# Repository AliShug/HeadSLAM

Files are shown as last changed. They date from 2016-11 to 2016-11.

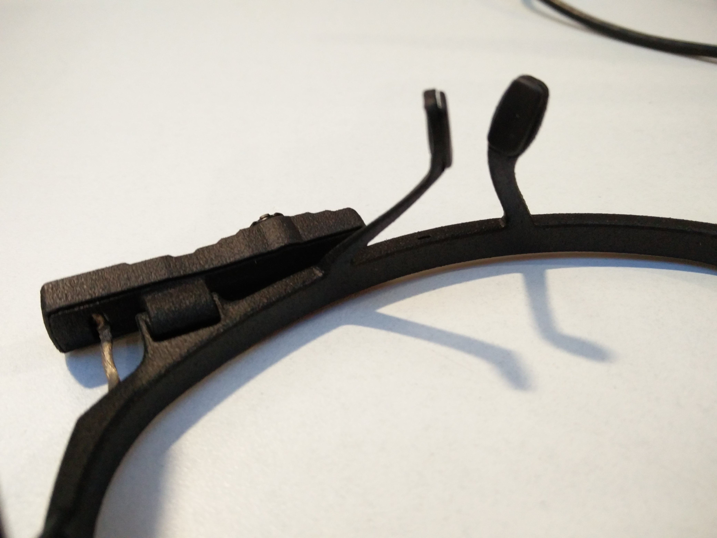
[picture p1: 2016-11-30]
reference/camera_back.jpg

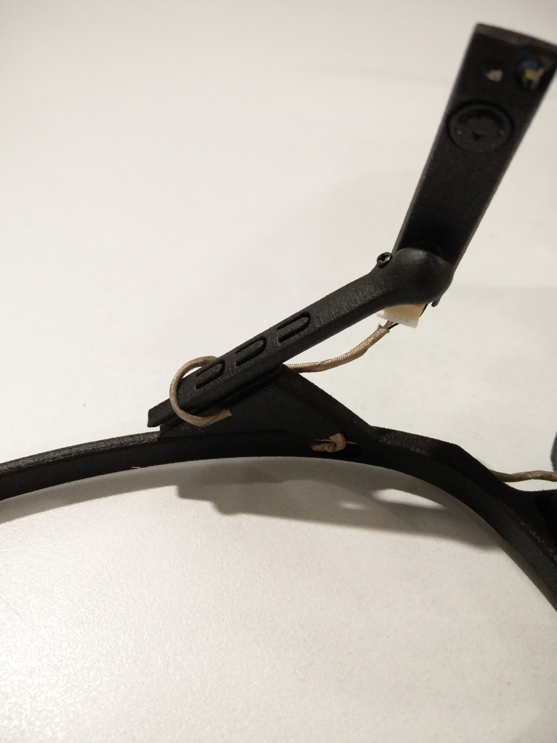
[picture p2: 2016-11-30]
reference/eye-tracker.jpg

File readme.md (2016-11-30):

This is a set of prototype design files for a head-mounted combined SLAM/eye-tracking system, based on the Pupil labs headset. The designs are intended to be 3D-printed - see [here](3d-printing.md) for more details.

# Files
Individual components are contained in Inventor part (IPT) files, with some files containing more than one solid body (these need to be separated out for 3D printing). Some parts are derived from others, which means changes to the root part affect the derived part. This is true for parts representing individual solids from a multi-body part, as well as some other parts: for example, the Pupil-FULL part derives from the Pupil part.

Assemblies show how the parts fit and connect together. An assembly is provided for each of the prototypes, with two different versions for the second prototype.

# Assembly
The designs use mainly metric M2 and some M3 screws and nuts. Slots are provided in several parts for M2 nuts, which should be filled by pushing these nuts into place before assembly.

The prototypes clamp directly onto the edges of the Pupil headset. Screw the clamps on most of the way before mounting, then line up the parts by matching the curve of the front of the headset to the curve in the mounting. Tighten the screws fully to secure the assembly.

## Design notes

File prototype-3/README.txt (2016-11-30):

Working prototype, uses a clamping mechanism to hold the entire assembled Xtion
heatsink, including the factory-mounted PCB and cameras.

The design sacrifices weight savings for ease of mounting and use; this
prototype should not require calibration and dissipates heat as well or better
than the fully assembled Xtion.

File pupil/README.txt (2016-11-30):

While care has been taken to be as accurate as possible, these models are
reverse-engineered using hand measurements and rough photographs of the pupil
headset, and as such they are APPROXIMATE. The actual headset may differ from
these designs by as much as a 1-2mm, notably in the precise shape of the curves
and the nose-rests.

The "full" model lacks the characteristic camera and eye-tracker, but shows
where these are mounted.

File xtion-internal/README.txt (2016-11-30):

While care has been taken to be as accurate as possible, these models are
reverse-engineered using hand measurements, and as such they are APPROXIMATE.
This mostly affects the heatsink, which was modelled with straight sides which
should in fact be slightly tapered.

The heatsink model lacks some holes and mounting points for the PCB. The
heatsink's precise design may also differ slightly between different models of
the Xtion.

With the exception of connection points, the PCB model lacks representation on
on-surface components. Care should be taken when designing e.g. mounts for the
PCB to account for the extra 1-2mm of clearance needed for these parts, on BOTH
sides of the board. Areas immediately (2-3mm) around the screw holes are clear
on both sides.

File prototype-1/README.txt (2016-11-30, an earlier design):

Lightweight design which mounts well (the clamps remained unchanged in the later
prototypes), but with several problems. The PCB was intended to be mounted flat,
which was impossible since the surface components on the board prevented it from
being placed flush. The mounting of the cameras and projector directly onto a
3D-printed part also proved impractical, since the Xtion would have to be
extensively re-calibrated.

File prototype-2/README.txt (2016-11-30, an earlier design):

This prototype still had the problem of requiring a difficult recalibration, and
didn't provide sufficient heat dissipation. A minor redesign allowed use of a
modified (cut-down) heatsink as part of the design, but removing the cameras
from their mountings (even when replacing them in their original positions)
would still have negatively affected calibration.

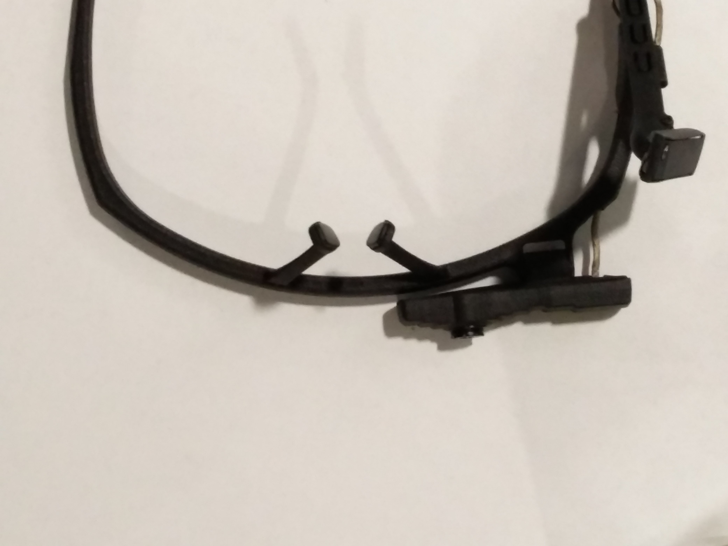
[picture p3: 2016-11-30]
reference/pupil_bottom_close.jpg

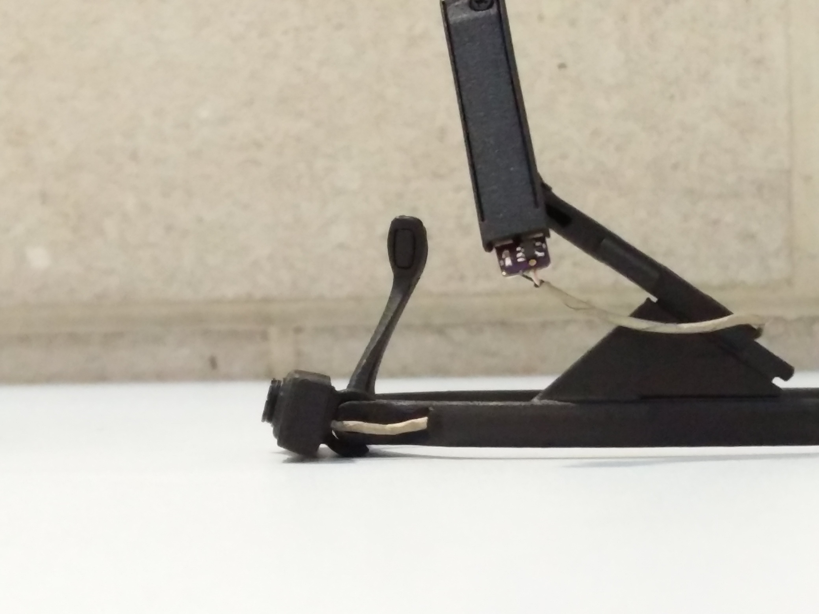
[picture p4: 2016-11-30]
reference/rest_side.jpg

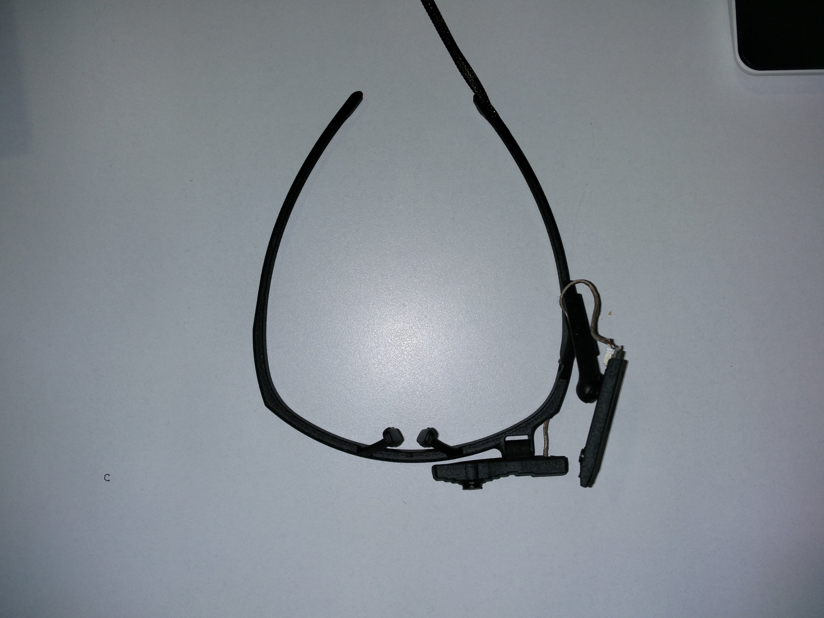
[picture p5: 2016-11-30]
reference/pupil_bottom.jpg

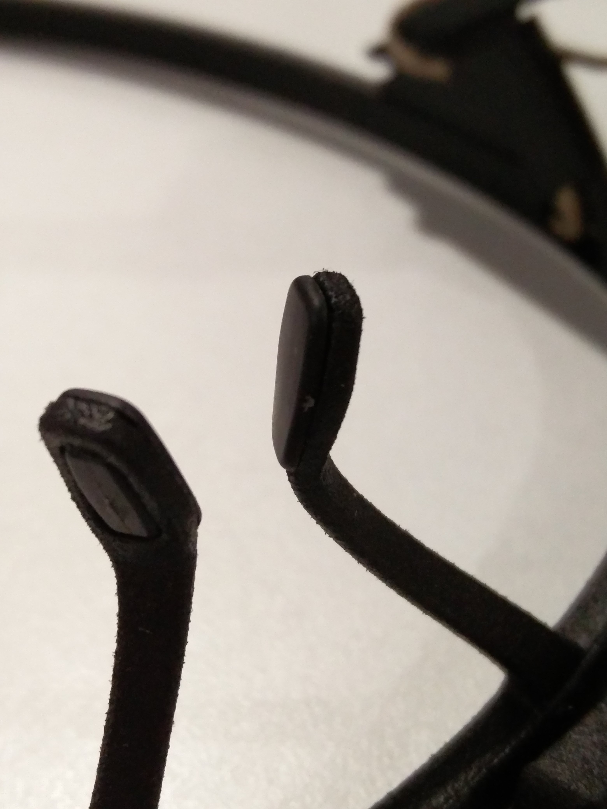
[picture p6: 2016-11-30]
reference/rest_pads.jpg

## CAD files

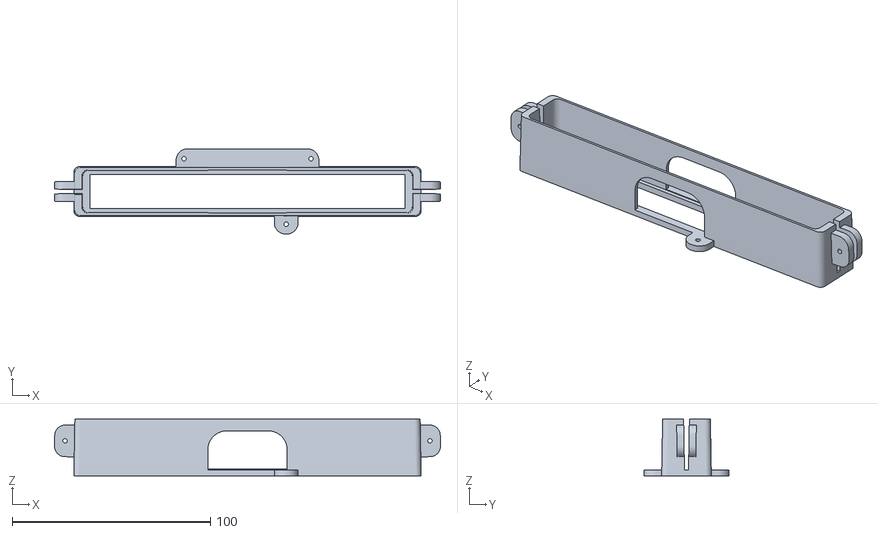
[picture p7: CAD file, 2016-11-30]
stl/final/xtion_heatsink_mount_FULL.stl
194.6 x 43.0 x 28.5

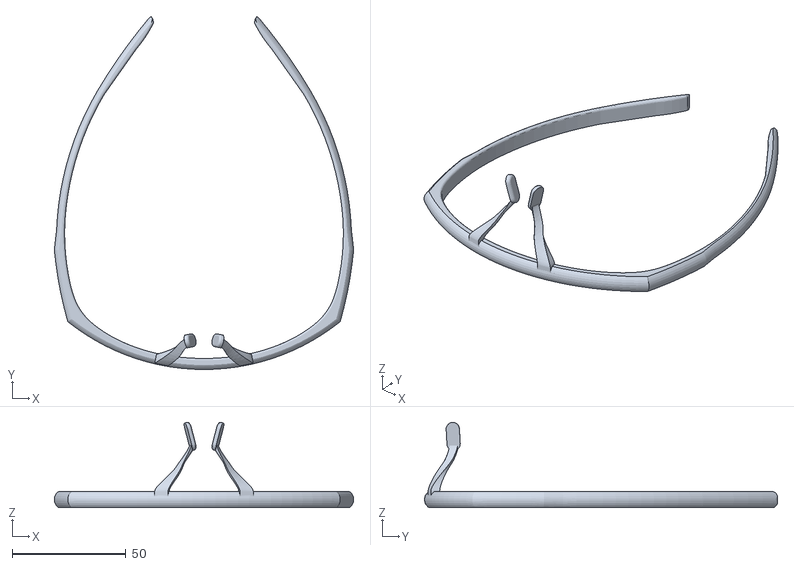
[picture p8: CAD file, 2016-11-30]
stl/pupil_frame.stl
131.9 x 155.5 x 37.6

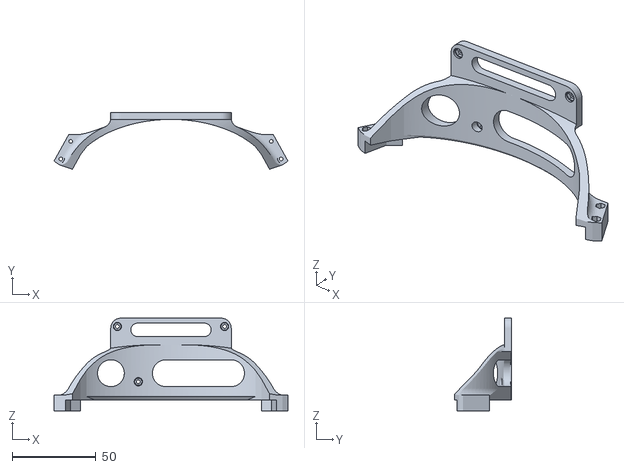
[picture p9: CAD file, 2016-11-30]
stl/final/head_mount_v3_core.stl
139.8 x 33.8 x 55.4

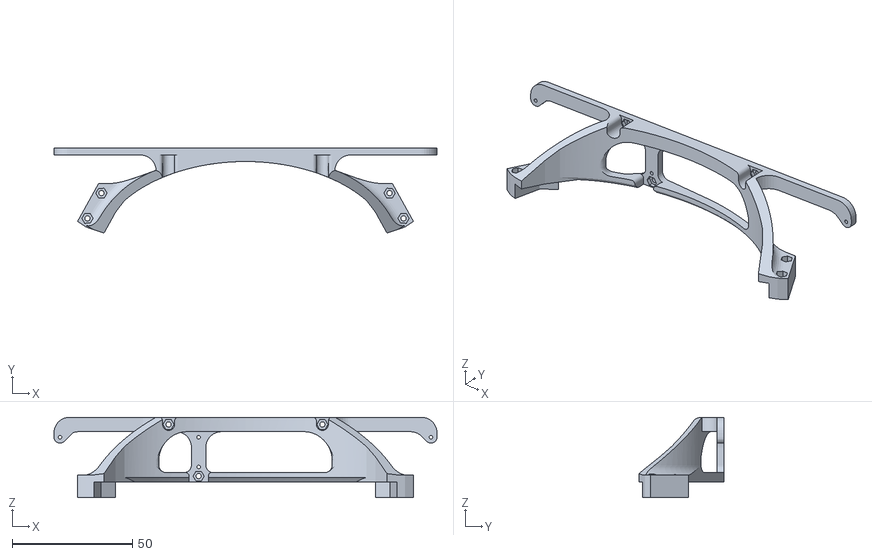
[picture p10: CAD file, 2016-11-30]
stl/mounting_core_v2.stl
159.4 x 35.5 x 33.5

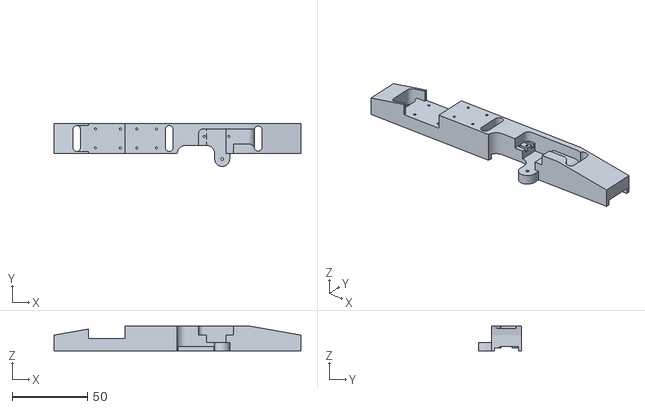
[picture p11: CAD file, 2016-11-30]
stl/xtion_custom.stl
164.0 x 28.6 x 16.3

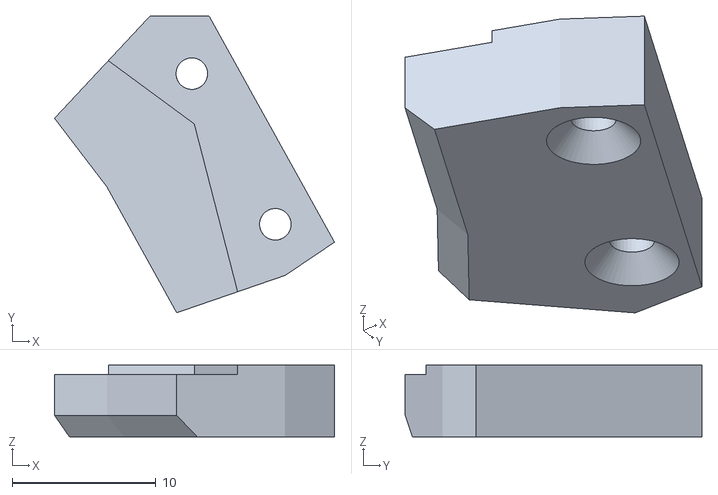
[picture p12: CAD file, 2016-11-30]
stl/mounting_clamp_r.stl
19.5 x 20.7 x 5.00

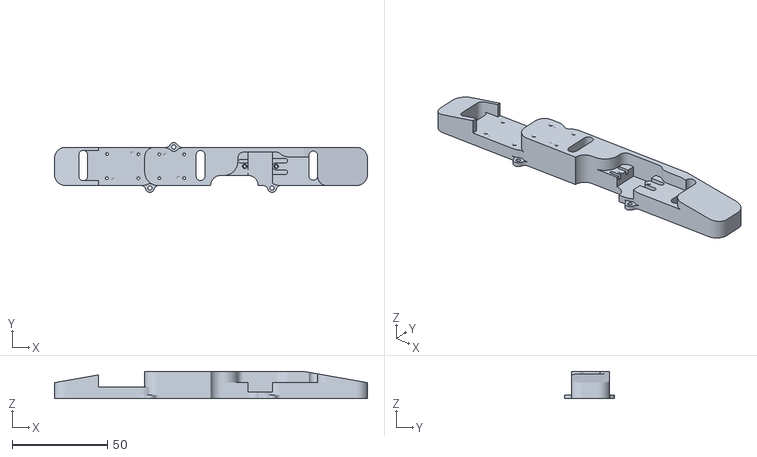
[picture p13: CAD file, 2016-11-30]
stl/xtion_custom_v2.stl
164.0 x 26.1 x 14.3

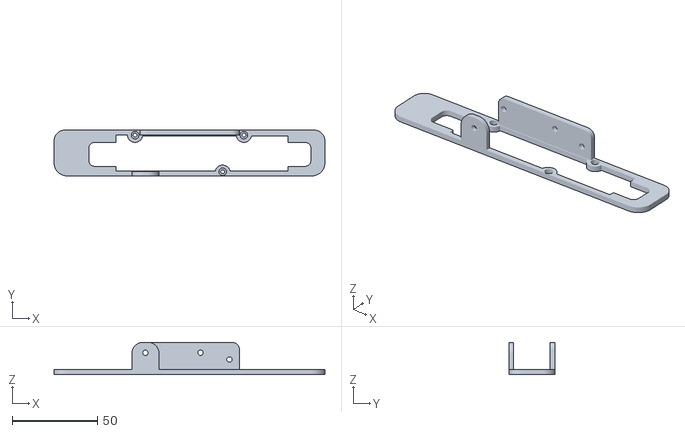
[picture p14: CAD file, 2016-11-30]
stl/xtion_custom_heatsink_mount.stl
159.4 x 27.0 x 19.0

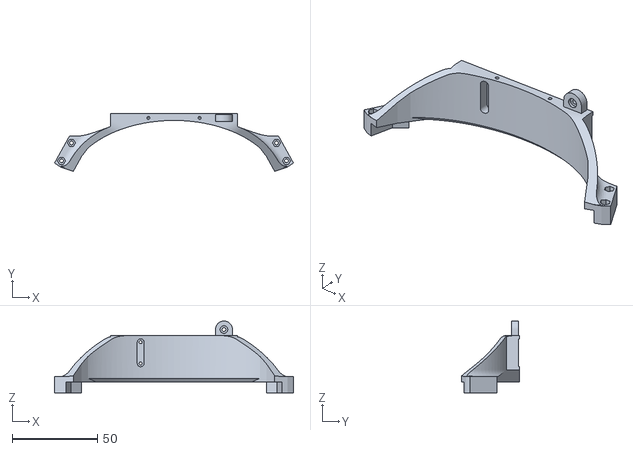
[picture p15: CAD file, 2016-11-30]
stl/mouting_core.stl
139.8 x 33.8 x 42.1

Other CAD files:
prototype-1/mounting.ipt
prototype-1/mounting_clamp_l.ipt
prototype-1/mounting_clamp_r.ipt
prototype-1/mouting_core.ipt
prototype-1/xtion_custom.ipt
prototype-1/xtion_custom_assembly.iam
prototype-2/head_mount_v2.ipt
prototype-2/mounting_core_v2.ipt
prototype-2/xtion_custom_assembly_v2.iam
prototype-2/xtion_custom_assembly_v2_heatsink_mod.iam
prototype-2/xtion_custom_heatsink_mount.ipt
prototype-2/xtion_custom_v2.ipt
prototype-2/xtion_heatsink_mod.ipt
prototype-3/head_mount_v3_FULL.ipt
prototype-3/head_mount_v3_core.ipt
prototype-3/xtion_custom_assembly_v3_FULL.iam
prototype-3/xtion_heatsink_mount_FULL.ipt
pupil/pupil_frame.ipt
pupil/pupil_frame_full.ipt
xtion-internal/xtion_heatsink.ipt
xtion-internal/xtion_internal.iam
xtion-internal/xtion_ir_cam.ipt
xtion-internal/xtion_mainboard.ipt
xtion-internal/xtion_projector.ipt
xtion-internal/xtion_rgb_cam.ipt

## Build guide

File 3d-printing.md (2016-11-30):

# 3D Printing
Use best practices for the printer you're working with - these are general guides for printing the parts in this repository.

## Conversion
### Export
Inventor part files (.IPT) must be exported to a 3D format, typically STL, to be "sliced" in a program like Cura and 3D printed. Exporting can be done using the file menu (*File->Export->CAD Format*), or using the 3D printing environment (*Environments->3D Printing*) in Inventor Pro. Make sure to use **millimetres** as the unit for exporting, to ensure the scaling of the part is accurate.

### Splitting parts
The main mounting part in each of the prototypes is comprised of three separate solid bodies (the core and two clamps) which must be printed separately. One way to do this is to derive a new part from a *single* solid body in the multi-body part, using *Manage->Make Part*. The isolated part can then be exported and printed as normal.

## Supports
Many of the parts have distinct overhangs and holes which **must** be supported when printing: please use support-generation options in your slicing program, and enable these supports for all surfaces - *not just from the printing bed*.

If your printer requires it, use a 'raft' for bed adhesion and level printing. On an Ultimaker 2/3 this isn't necessary, but you should still use a 'brim' for the larger parts.

## Orientation
The parts should be oriented on the printing bed to minimise the amount of support necessary, and either in line with or at 90 degrees to any screw holes in the part (don't print at a 45 degree slant!). If the part has a large, flat surface, use this as the base.

## Quality
These parts need to fit together fairly precisely, and must be consistently strong in order to flex and mount properly. Use 0.1mm (100 micron) layers, and a nozzle no larger than 0.6mm. Don't push the printer's speed above recommended limits, as this will weaken and deform the part.

PLA material was used for the prototypes and should work fine for most purposes. However, PLA isn't particularly durable and weakens rapidly with heating, so if you want to make a durable prototype, or use hot glue on parts, then you should investigate ABS or other more advanced materials for printing.

## Post-processing
Remove support material by force - pliers help with this. Holes need to be cleared of support material, using a small screwdriver head or an undersized drill - don't bore out the holes too much, though.

Some holes may be slightly tight, depending on the printer and print settings. You can push or thread screws through.
